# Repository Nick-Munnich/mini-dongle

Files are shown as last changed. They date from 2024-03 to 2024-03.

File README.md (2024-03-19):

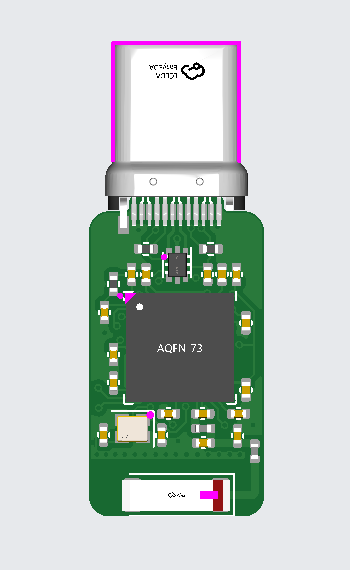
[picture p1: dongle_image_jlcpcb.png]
Render using JLCPCB's PCBA visualiser Render using JLCPCB's PCBA visualiser because KiCAD doesn't have the MOLEX USB connector 3d model


This is an attempt to make as miniature of a dongle for ZMK as is realistically possible. PCB size: 20.66mmx11.3mm

By realistically, I mean to not be completely unaffordable to produce. 
It could be made smaller through the use of components on both sides and via-in-pad, but this would raise the cost by a large degree. Likewise for reducing the width of traces even further - theoretically sound and wouldn't have any issues with the current levels we are dealing with, but financially unviable.

Despite my best efforts, it turns out to be financially unviable for PCBA -- in large enough quantities it would be fine, but thanks to FCC/CE certification the amount of orders needed would be unrealistic for something like this.

However, it should be perfectly fine for someone who has a hot plate and happens to be ordering parts from a site such as digikey/mouser already. If someone has a reflow oven and wants me to design a version that has components on both sides, let me know.

Note that the PCB antenna trace width to get the correct impedence was calculated using JLCPCB's tool, so I cannot recommend ordering this from anywhere else without first redoing said calculation and adjusting the width appropriately.

Disclaimer: I am not a professional RF engineer, I merely followed the schematics on the datasheets for the components as closely as possible. I am fairly confident that it works, but there is always the chance of an error as it has not been tested.

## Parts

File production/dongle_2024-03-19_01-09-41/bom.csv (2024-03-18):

Designator | Footprint | Quantity | Value | LCSC Part #
AE1 | Johanson_2450AT43F0100 | 1 | Antenna
C1, C2 | 0402 | 2 | 15pF | C1548
C11 | 0402 | 1 | 100pF | C23733
C12, C31, C5, C7, C8 | 0402 | 5 | 100nF | C23733
C14, C15 | 0402 | 2 | 1uF | C23733
C19, C20, C6 | 0402 | 3 | 4.7uF | C23733
C3, C30 | 0402 | 2 | 0.8pF | C1550
C4 | 0402 | 1 | 0.5pF | C1550
C9 | 0402 | 1 | 820pF | C23733
L1 | 0402 | 1 | 4.7nH | C14033
L3 | 0402 | 1 | 5.6nH
P1 | USB_C_Plug_Molex_105444 | 1 | USB_C_Plug_USB2.0
R1 | 0402 | 1 | 2.2
R4, R5 | 0402 | 2 | 5.1K
TP1 | TestPoint_Pad_2.0x2.0mm | 1 | SWD
TP2 | TestPoint_Pad_2.0x2.0mm | 1 | SWC
U1 | SOT-666 | 1 | USBLC6-2P6
U2 | Nordic_AQFN-73-1EP_7x7mm_P0.5mm | 1 | nRF52840 | C190794
Y1 | Crystal_SMD_2016-4Pin_2.0x1.6mm | 1 | 32MHz | C255896

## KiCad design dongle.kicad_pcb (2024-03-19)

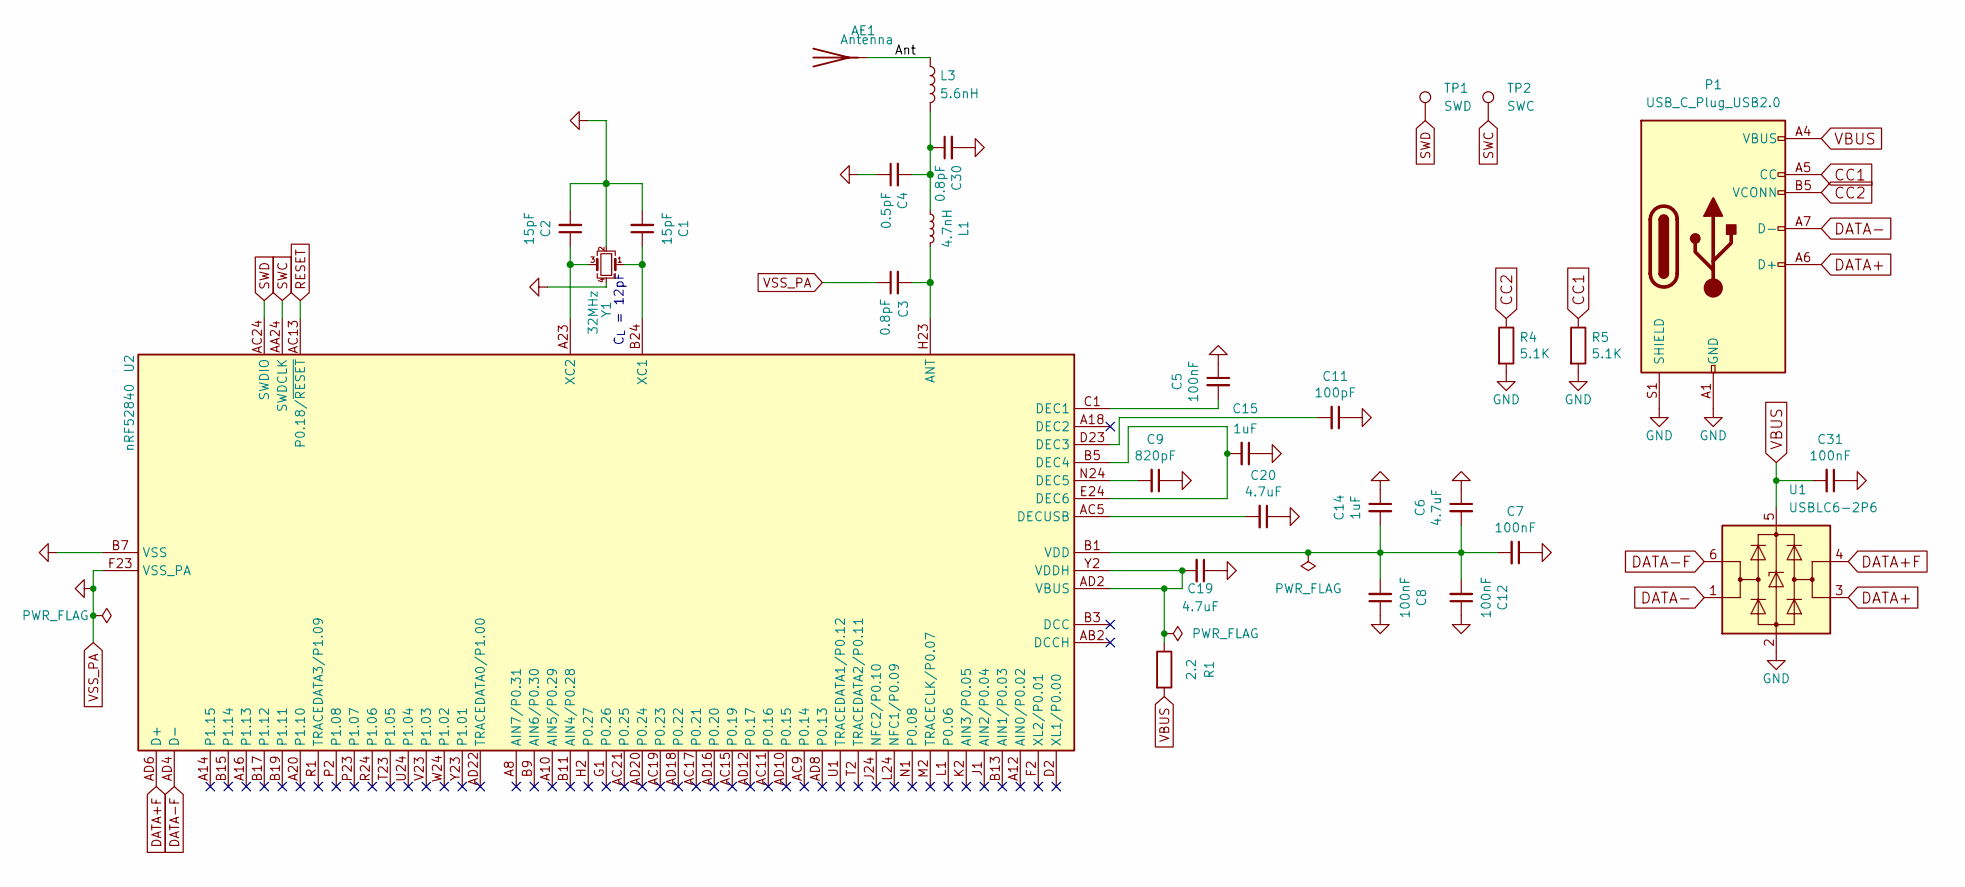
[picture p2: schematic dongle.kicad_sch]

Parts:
AE1: Antenna; Johanson_2450AT43F0100
C1, C2: 15pF; C_0402_1005Metric; Manufacturer Part CL05C150JB51PNC; LCSC Part C1548
C3, C30: 0.8pF; C_0402_1005Metric; Manufacturer Part CL05C010CB5NNNC; LCSC Part C1550
C4: 0.5pF; C_0402_1005Metric; Manufacturer Part CL05C010CB5NNNC; LCSC Part C1550
C5, C7, C8, C12, C31: 100nF; C_0402_1005Metric; Manufacturer Part CL05A475KP5NRNC; LCSC Part C23733
C6, C19, C20: 4.7uF; C_0402_1005Metric; Manufacturer Part CL05A475KP5NRNC; LCSC Part C23733
C9: 820pF; C_0402_1005Metric; Manufacturer Part CL05A475KP5NRNC; LCSC Part C23733
C11: 100pF; C_0402_1005Metric; Manufacturer Part CL05A475KP5NRNC; LCSC Part C23733
C14, C15: 1uF; C_0402_1005Metric; Manufacturer Part CL05A475KP5NRNC; LCSC Part C23733
L1: 4.7nH; L_0402_1005Metric; Manufacturer Part MLG1005S3N9BT000; LCSC Part C14033
L3: 5.6nH; L_0402_1005Metric
P1: USB_C_Plug_USB2.0; USB_C_Plug_Molex_105444
R1: 2.2; R_0402_1005Metric
R4, R5: 5.1K; R_0402_1005Metric
TP1: SWD; TestPoint_Pad_2.0x2.0mm
TP2: SWC; TestPoint_Pad_2.0x2.0mm
U1: USBLC6-2P6; SOT-666
U2: nRF52840; Nordic_AQFN-73-1EP_7x7mm_P0.5mm; Manufacturer Part NRF52840-QIAA-R; LCSC Part C190794
Y1: 32MHz; Crystal_SMD_2016-4Pin_2.0x1.6mm; Manufacturer Part Q22FA1280001800; LCSC Part C255896

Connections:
/Ant: AE1.1 (A), L3.1
CC1: P1.A5 (CC), R5.1
CC2: P1.B5 (VCONN), R4.1
DATA+: P1.A6 (D+), U1.3 (I/O2)
DATA+F: U1.4 (I/O2), U2.AD6 (D+)
DATA-: P1.A7 (D-), U1.1 (I/O1)
DATA-F: U1.6 (I/O1), U2.AD4 (D-)
unnamed: C6.2, C7.2, C8.2, C12.2, C14.2, U2.A22 (VDD), U2.AD14 (VDD), U2.AD23 (VDD), U2.B1 (VDD), U2.W1 (VDD)
unnamed: C4.2, C30.1, L1.1, L3.2
unnamed: C3.2, L1.2, U2.H23 (ANT)
unnamed: C5.2, U2.C1 (DEC1)
unnamed: C11.2, U2.D23 (DEC3)
unnamed: C15.2, U2.B5 (DEC4), U2.E24 (DEC6)
unnamed: C9.2, U2.N24 (DEC5)
unnamed: C20.2, U2.AC5 (DECUSB)
unnamed: C19.2, R1.1, U2.AD2 (VBUS), U2.Y2 (VDDH)
unnamed: C1.1, U2.B24 (XC1), Y1.1
unnamed: C2.1, U2.A23 (XC2), Y1.3
RESET: U2.AC13 (P0.18/~RESET)
SWC: TP2.1, U2.AA24 (SWDCLK)
SWD: TP1.1, U2.AC24 (SWDIO)
VBUS: C31.2, P1.A4 (VBUS), P1.A9 (VBUS), P1.B4 (VBUS), P1.B9 (VBUS), R1.2, U1.5 (VBUS)
VSS_PA: C1.2, C2.2, C3.1, C4.1, C5.1, C6.1, C7.1, C8.1, C9.1, C11.1, C12.1, C14.1, C15.1, C19.1, C20.1, C30.2, C31.1, P1.A1 (GND), P1.A12 (GND), P1.B1 (GND), P1.B12 (GND), P1.S1 (SHIELD), R4.2, R5.2, U1.2 (GND), U2.B7 (VSS), U2.EP (VSS), U2.F23 (VSS_PA), Y1.2, Y1.4

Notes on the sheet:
C_{L} = 12pF

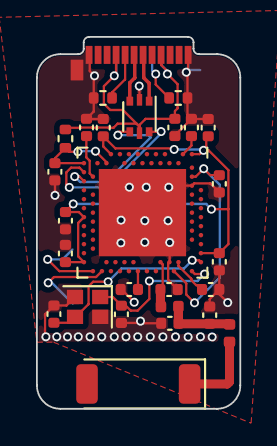
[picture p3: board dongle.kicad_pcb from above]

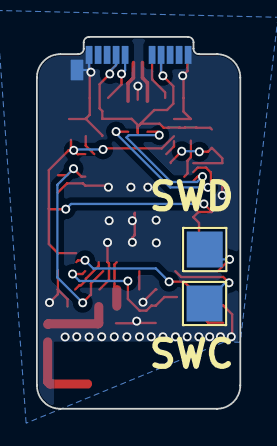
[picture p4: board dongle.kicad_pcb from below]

Board: 2 copper layers, 11.3 x 20.7 mm, 29 parts (2 on the bottom side), 22 nets.

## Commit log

2024-03-19 added readme
    [bom.csv, designators.csv, positions.csv]
2024-03-19 added production files
    [bom.csv, designators.csv, positions.csv]
2024-03-19 forgot a silkscreen marker
    [bom.csv, designators.csv, dongle.kicad_pcb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]
